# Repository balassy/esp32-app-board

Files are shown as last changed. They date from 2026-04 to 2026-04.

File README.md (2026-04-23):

# ESP32 App Board

A custom PCB designed to quickly start projects based on the ESP32-WROOM-32 module. It's bigger than a fully customized PCB, but smaller than a generic ESP32 breakout board.

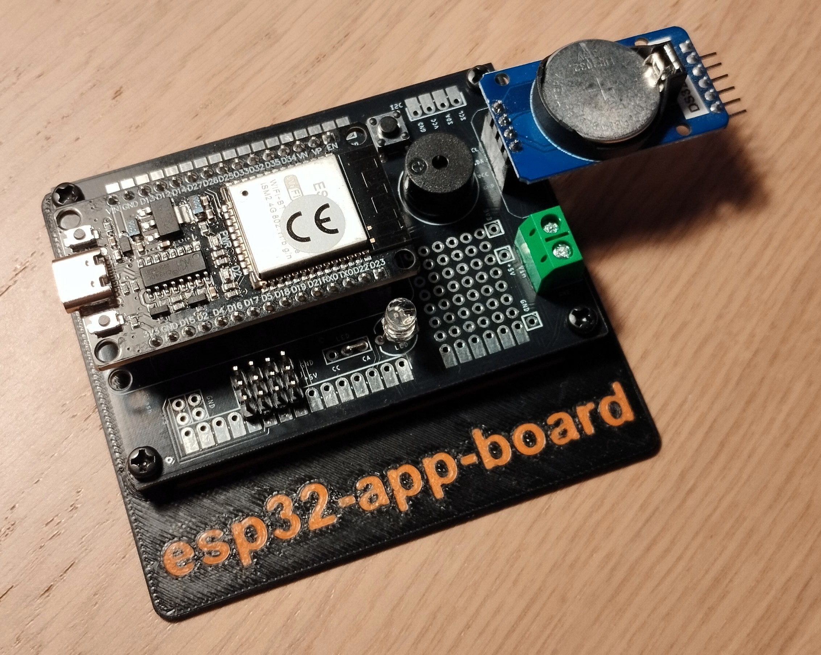
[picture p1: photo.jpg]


## Features

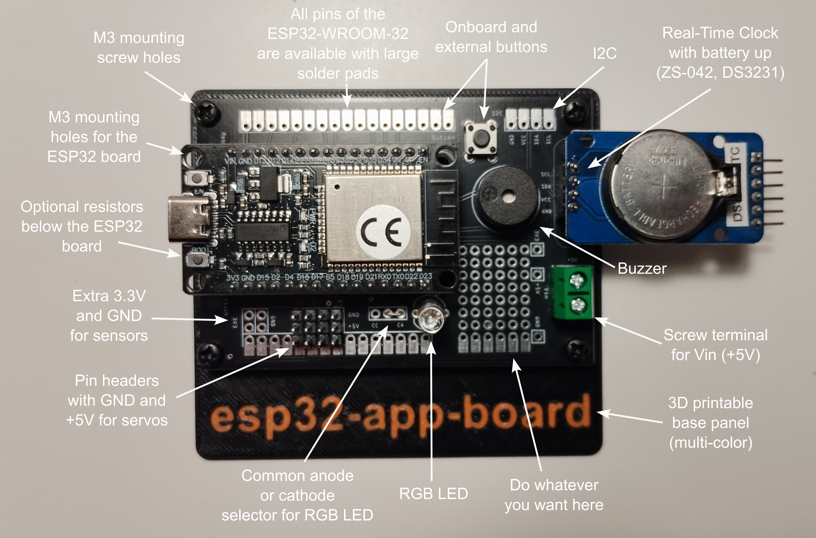
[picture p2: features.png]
Features


- Socket for the ESP32-WROOM-32 module.
- Separate pin headers for all 30 pins of the ESP32-WROOM-32 module with large solder pads on the top layer.
- Screw terminal for the +5V Vin and GND pins.
- 2+1 extra pins for the +3.3V pin.
- 2+1+4 extra pins for the GND pin.
- 2+1+4 extra pins for the +5V pin. 
- 4 GND-5V-GPIO pins positioned to easily connect 4 servos.
- Buzzer.
- Tactile button with pin headers for a parallel external button. 
- 5 GPIO ports with custom resistors (e.g. for external LEDs).
- ZS-042 Real Time Clock module, mounted with battery up.
- Pin headers for external I2C module.
- 5mm RGB LED, either common anode or common cathode.
- 6×8 pin matrix for additional parts.
- 3mm diameter mounting screw holes.

## GPIO Pins

- Button: D32 (other pin connected to GND).
- Buzzer positive (+): D23 (other pin connected to GND).
- Pins with custom resistor: D12, D13, D14, D26, D27. The resistors are marked as R12, R13, R14, R26 and R27 accordingly. Shortcut wires must be installed if these pins are used directly.
- RGB LED: D12, D13, D14. The LED pin header MUST be used to select between common anode (CA) and common cathode (CC) LEDs.
- I2C: SDA D21, SCL D22. 

Which pin to use? Read more: https://randomnerdtutorials.com/esp32-pinout-reference-gpios/

## PCB

Top view:

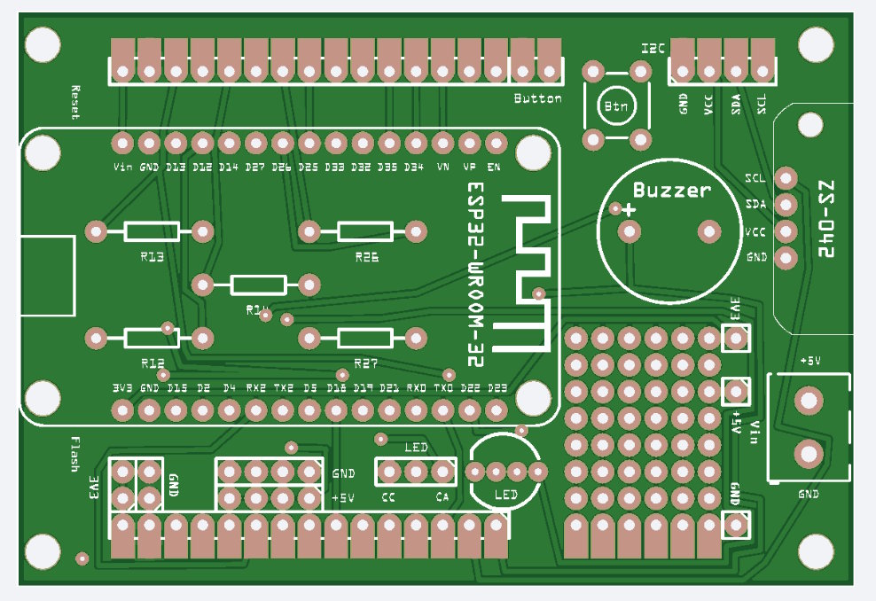
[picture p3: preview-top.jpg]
Preview top


Bottom view:

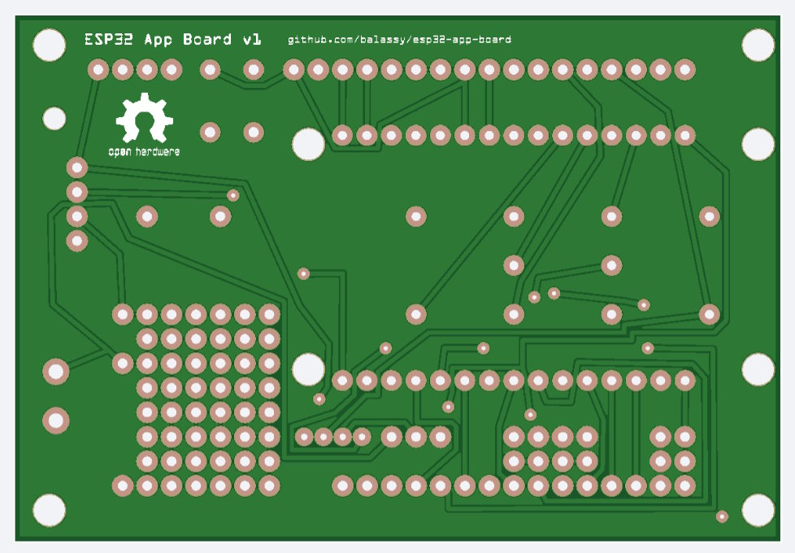
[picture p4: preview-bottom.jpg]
Preview bottom


## Wiring

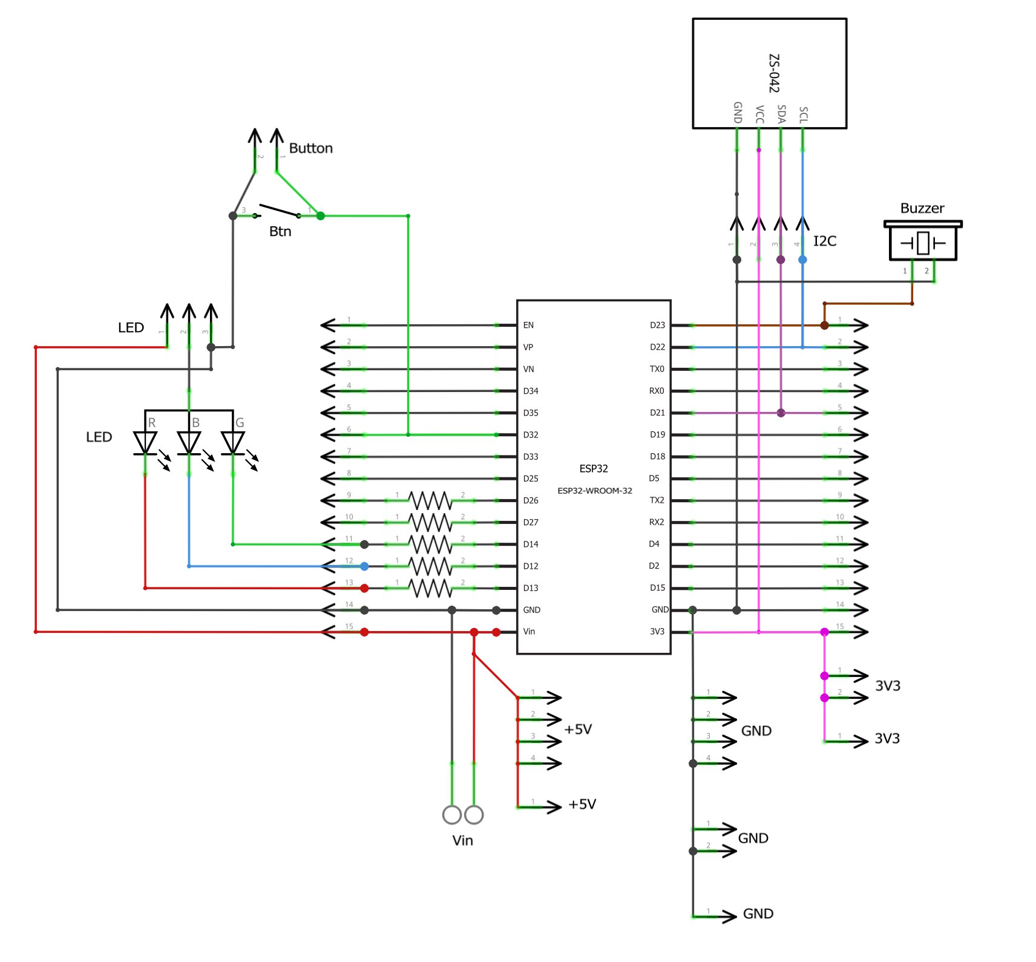
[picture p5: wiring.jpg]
Wiring


## Dimensions

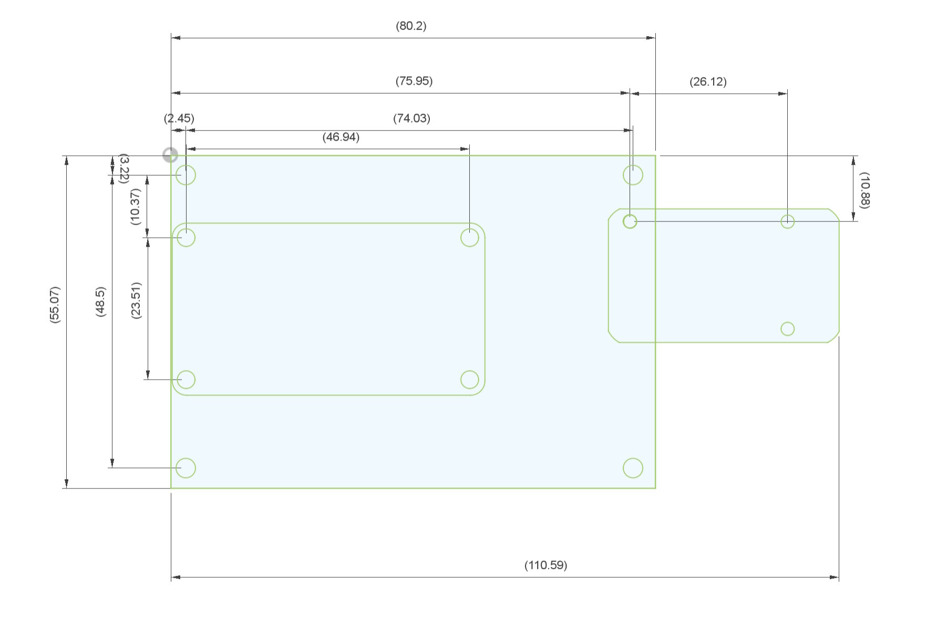
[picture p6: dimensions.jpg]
Dimensions


The mounting holes of the PCB are 3mm diameter.

The mounting holes of the ZS-042 module are 2mm diameter.

The Fusion 360 model in the [3d](./3d/) folder contains these dimensions.

## What's in this repo

- [3d](./3d/): Fusion 360 models used to generate the dimension drawing, and a 3D printable stand. You can use it to build a custom case for this panel.
- [code](./code/): Simple source code to manual test the features of the PCB.
- [gerber](./gerber/): The Fritzing-generated Gerber files that can be used to manufacture the PCB. 
- [parts](./parts/): The custom Fritzing parts used to build this board.
- [source](./source/): The original, editable source file of this PCB, created with Fritzing.

## Parts used

The following parts have been used in this project:

- 2-pin screw terminal connector with 5mm spacing, created by [Blue](https://forum.fritzing.org/t/35-new-edited-parts/6361).
- ZS-042 Real Time Clock module, created by [György Balássy](https://github.com/balassy/fritzing-parts).
- ESP32-WROOM-32 module, created by [György Balássy](https://github.com/balassy/fritzing-parts).

You can find these in the [parts](./parts/) folder, and they must be imported into Fritzing before opening the PCB.

## Autoroute steps

Follow these steps to generate the PCB wiring:

1. Routing --> Autorouter/DRC Settings: Custom - Trace width: thin (16 mil)
2. Routing --> Select All Autoroutable Traces --> Delete
3. Routing --> Select All Vias --> Delete
4. Routing --> Autoroute
5. Routing --> Show Unrouted. `There are no unrouted connections` message should appear. If not, try increasing the iteration count in the Autoroute dialog.
6. Routing --> Design Rules Check (DRC). Click the errors one by one to highlight the problem with red (they are hard to see). Hide the silkscreen and the unrelated copper layer and reposition the wires. Turn off View --> Aligh to Grid.
7. Re-run the Design Rules Check until `Your sketch is ready for production` message appers.
8. Routing --> Ground Fill --> Ground Fill (top and bottom).

## Verify the layout

Follow these steps to print the design onto paper with 1:1 dimentions:

1. In Fritzing click File --> Export --> as Image --> SVG. 
2. Open the SVG in Inkscape or other editing program.
3. Remove the unnecessary items (e.g. Fritzing logo)
4. Change the Format to A4 in Document Properties.
5. Print to paper.

## Generate Gerber files

The latest Gerber files to manufacture the PCB is available in the [gerber](./gerber/) folder.

To re-generate them in Fritzing click File --> Export --> for Production --> Extended Gerber, then select the [gerber](./gerber/) folder.

## Known issues

For known issues see the [GitHub Issues](https://github.com/balassy/esp32-app-board/issues) of this project.

## About the author

This project is created and maintained by [György Balássy](https://www.linkedin.com/in/balassy).

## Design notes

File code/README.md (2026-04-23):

# Tester for the esp32-app-board

The [esp32_app_bpard_tester](./esp32_app_board_tester/) folder contains sample code that can be used to manual test the various features of this board.

## Prerequisites

To test the Real-Time Clock feature of the board install the following libraries:
- [Adafruit BusIO by Adafruit](https://github.com/adafruit/Adafruit_BusIO)
- [RTCLib by Adafruit](https://github.com/adafruit/RTClib)

## Configuration

Select which feature you want to test by setting the value of the `#define`-d constant at the top of the file to `1`. 

For example to test the RGB LED:

```cpp
#define TEST_RGB_LED_CA 1
```

NOTE: The tests are not designed to execute at the same time, so all other constant must be set to `0` !

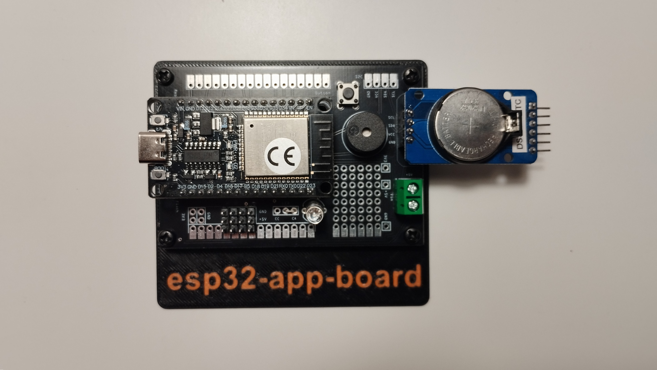
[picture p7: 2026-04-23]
features.jpg

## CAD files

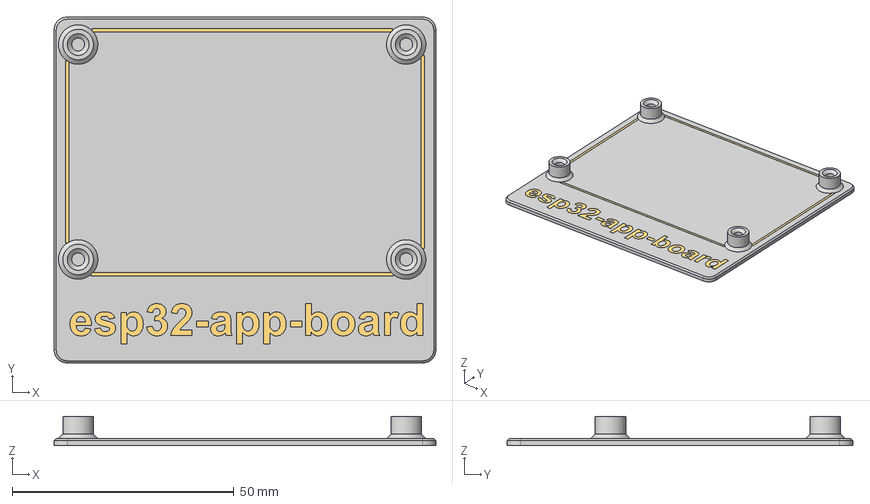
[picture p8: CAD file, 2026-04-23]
3d/esp32-app-board - stand.step
86.2 x 78.1 x 6.60 mm

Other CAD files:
3d/esp32-app-board - stand.3mf
3d/esp32-app-board - stand.f3d
3d/esp32-app-board.f3d

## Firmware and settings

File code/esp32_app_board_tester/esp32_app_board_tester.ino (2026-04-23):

// Test configuration:
#define TEST_ONBOARD_LED 0
#define TEST_RGB_LED_CA 1
#define TEST_BUTTON 0
#define TEST_BUZZER 0
#define TEST_RTC 0
#define TEST_SERVO 0
 
// App configuration:
inline constexpr unsigned long SERIAL_BAUD_RATE = 115200;

// Pin configuration:
inline constexpr uint8_t PIN_ONBOARD_LED = 2;
inline constexpr uint8_t PIN_RGB_LED_RED = 13;
inline constexpr uint8_t PIN_RGB_LED_GREEN = 12;
inline constexpr uint8_t PIN_RGB_LED_BLUE = 14;
inline constexpr uint8_t PIN_BUTTON = 32;
inline constexpr uint8_t PIN_BUZZER = 23;
inline constexpr uint8_t PIN_RTC_SDA = 21;
inline constexpr uint8_t PIN_RTC_SCL = 22;
inline constexpr uint8_t PIN_SERVO = 17;   // 4, 5, 16, 17

#include <Wire.h>        // I2C library required by the RTC module.
#include "RTClib.h"      // RTC library by Adafruit
#include <ESP32Servo.h>  // To control the SG90 servo motors

RTC_DS3231 rtc;
Servo servo;

void setup() {
  initSerial();

  #if TEST_ONBOARD_LED
    initOnboardLed();
  #endif

  #if TEST_RGB_LED_CA
    initRgbLed();
  #endif

  #if TEST_BUTTON
    initButton();
  #endif

  #if TEST_BUZZER
    initBuzzer();
  #endif

  #if TEST_RTC
    initRtc();
  #endif

  #if TEST_SERVO
    initServo();
  #endif
}

void loop() {
  #if TEST_ONBOARD_LED
    loopOnboardLed();
  #endif

  #if TEST_RGB_LED_CA
    loopRgbLed();
  #endif

  #if TEST_BUTTON
    loopButton();
  #endif

  #if TEST_RTC
    loopRtc();
  #endif

  #if TEST_SERVO
    loopServo();
  #endif  
}


void initSerial() {
  Serial.begin(SERIAL_BAUD_RATE);
  Serial.println();
  Serial.println(F("initSerial: Initializing serial connection DONE."));
}

void initOnboardLed() {
  Serial.println(F("initOnboardLed: Initializing onboard LED..."));

  pinMode(PIN_ONBOARD_LED, OUTPUT);

  Serial.println(F("initOnboardLed: Initializing onboard LED DONE."));
}

void initRgbLed() {
  Serial.println(F("initRgbLed: Initializing RGB LED..."));

  pinMode(PIN_RGB_LED_RED, OUTPUT);
  pinMode(PIN_RGB_LED_GREEN, OUTPUT);
  pinMode(PIN_RGB_LED_BLUE, OUTPUT);

  // Turn off.
  digitalWrite(PIN_RGB_LED_RED, HIGH);
  digitalWrite(PIN_RGB_LED_GREEN, HIGH);  
  digitalWrite(PIN_RGB_LED_BLUE, HIGH);  

  Serial.println(F("initRgbLed: Initializing RGB LED DONE."));
}

void initButton() {
  Serial.println(F("initButton: Initializing button..."));
  pinMode(PIN_BUTTON, INPUT_PULLUP);
  Serial.println(F("initButton: Initializing button DONE."));
}

void initBuzzer() {
  Serial.println(F("initBuzzer: Initializing buzzer..."));
  pinMode(PIN_BUZZER, OUTPUT);
  digitalWrite(PIN_BUZZER, HIGH);
  delay(3000);
  digitalWrite(PIN_BUZZER, LOW);
  Serial.println(F("initBuzzer: Initializing buzzer DONE."));
}

void initRtc() {
  Serial.println(F("initRtc: Initializing Real-Time Clock module..."));
  Wire.begin(PIN_RTC_SDA, PIN_RTC_SCL);
  if (!rtc.begin()) {
    Serial.println(F("initRtc: Couldn't find RTC"));
    while (1);
  }
  Serial.println(F("initRtc: Initializing Real-Time Clock module DONE."));
}

void initServo() {
  Serial.println(F("initServo: Initializing servo motor..."));
  servo.attach(PIN_SERVO);
  Serial.println(F("initServo: Initializing servo motor DONE."));
} 

void loopOnboardLed() {
  Serial.println(F("loopOnboardLed: Turning on..."));
  digitalWrite(PIN_ONBOARD_LED, HIGH);
  delay(1000);

  Serial.println(F("loopOnboardLed: Turning off..."));
  digitalWrite(PIN_ONBOARD_LED, LOW);
  delay(1000);   
}

void loopRgbLed() {
  Serial.println(F("loopRgbLed: Turning on red..."));
  digitalWrite(PIN_RGB_LED_RED, LOW);
  delay(500);
  digitalWrite(PIN_RGB_LED_RED, HIGH);
  delay(500);
  Serial.println(F("loopRgbLed: Turning on green..."));
  digitalWrite(PIN_RGB_LED_GREEN, LOW);
  delay(500);
  digitalWrite(PIN_RGB_LED_GREEN, HIGH);
  delay(500);
  Serial.println(F("loopRgbLed: Turning on blue..."));
  digitalWrite(PIN_RGB_LED_BLUE, LOW);
  delay(500);
  digitalWrite(PIN_RGB_LED_BLUE, HIGH);
  delay(500);
  Serial.println(F("loopRgbLed: Turning on red and blue..."));
  digitalWrite(PIN_RGB_LED_RED, LOW);
  digitalWrite(PIN_RGB_LED_BLUE, LOW);
  delay(500);
  digitalWrite(PIN_RGB_LED_RED, HIGH);
  digitalWrite(PIN_RGB_LED_BLUE, HIGH); 
  delay(500);    
}

void loopButton() {
  if(digitalRead(PIN_BUTTON) == LOW) {
    Serial.println(F("loopButton: Pressed"));
  } 
}

void loopRtc() {
  DateTime currentTime = rtc.now();
  printDateTime(currentTime);
  delay(1000);
}

void loopServo() {
  moveServoTo(1);
  moveServoTo(170);
}

void printDateTime(const DateTime &dt) {
  char formattedDateTime[32];
  snprintf(formattedDateTime, sizeof(formattedDateTime), "RTC: %04d.%02d.%02d. %02d:%02d:%02d",
           dt.year(), 
           dt.month(), 
           dt.day(),
           dt.hour(), 
           dt.minute(), 
           dt.second());
  Serial.println(formattedDateTime);
}

void moveServoTo(int newPosition) {
  newPosition = constrain(newPosition, 0, 180);

  // Check if the servo is properly initialized.
  if (!servo.attached()) {
    Serial.println(F("moveServoTo: Servo cannot move, because it is not attached!"));
    return;
  }

  // Get current servo position (0-180).
  int currentPosition = servo.read();

  Serial.println(String(F("moveServoTo: Moving servo from position ")) + String(currentPosition) +
                 String(F(" to position ")) + String(newPosition));

  // Unknown current position -> write target directly
  if (currentPosition < 0 || currentPosition > 180) {
    servo.write(newPosition);
    return;
  }

  // Do not move if already in position.
  if (currentPosition == newPosition) {
    return;
  }

  // Determine moving direction.
  int step = (newPosition > currentPosition) ? 1 : -1;

  for (int pos = currentPosition; pos != newPosition; pos += step) {
    servo.write(pos); 
    delay(2);
  }

  // Ensure final position exactly set.
  servo.write(newPosition);
}

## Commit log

2026-04-06 feat: v1 complete
    [ESP32-app-board.fzz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]
2026-04-07 fix: repositioned traces reported by JLCPCB (source only)
    [ESP32-app-board.fzz]
2026-04-23 feat(3d): added 3D printable, multi-color stand
    [esp32-app-board - stand.3mf, esp32-app-board - stand.f3d, esp32-app-board - stand.step]
2026-04-23 test: added sample tester code
2026-04-23 fix: pushing the latest version of the wiring
    [ESP32-app-board.fzz]
